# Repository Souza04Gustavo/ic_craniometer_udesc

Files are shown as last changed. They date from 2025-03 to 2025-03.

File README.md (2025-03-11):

# Craniômetro Digital - Projeto de Pesquisa UDESC (CCT & CEFID)

## Sobre o Projeto

Este repositório contém o desenvolvimento de um craniômetro digital, um protótipo inovador criado para auxiliar medições cranianas de bebês com maior precisão e eficiência em comparação com métodos manuais. O projeto é fruto de uma parceria entre a Universidade do Estado de Santa Catarina (UDESC) - Centro de Ciências Tecnológicas (CCT), Joinville, e a UDESC - Centro de Ciências da Saúde e do Esporte (CEFID). O desenvolvimento foi realizado por Gustavo de Souza e Grasiela Ferreira.

## Motivação

A medição da cabeça de bebês é um parâmetro essencial para monitoramento do crescimento e identificação de possíveis alterações no desenvolvimento craniano. Métodos tradicionais, como o uso de fita métrica, estão sujeitos a variações e imprecisões humanas. O craniômetro digital foi desenvolvido para:

Otimizar medições em clínicas e hospitais;

Reduzir erros humanos ao proporcionar um método padronizado e automatizado;

Aumentar a precisão nas medições cranianas;

Facilitar a obtenção e o registro dos dados para acompanhamento do crescimento infantil.

## Visão superior do protótipo

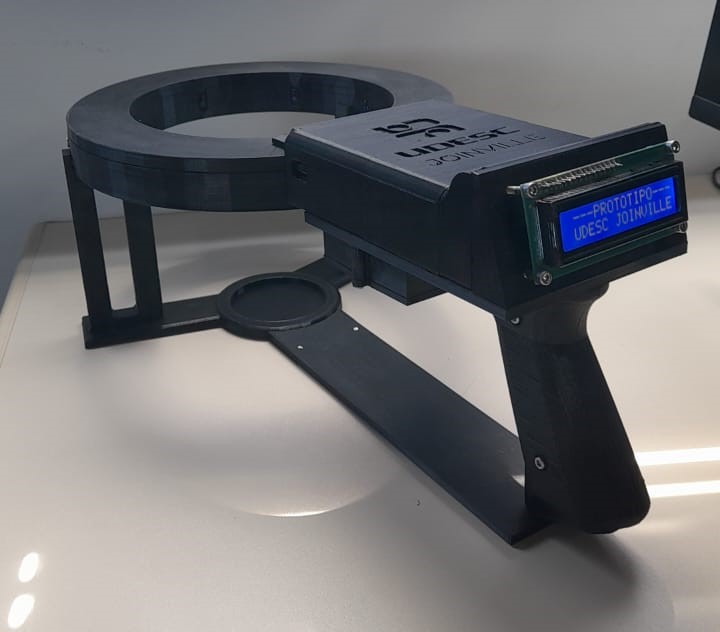
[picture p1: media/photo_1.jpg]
equipament photo


## Componentes Utilizados

| Componente | Descrição |
|---|---|
|**TCRT5000 (x8)** | Sensores infravermelhos para medir distâncias  |
|**MPU6050** | Módulo acelerômetro e giroscópio para estabilidade |
|**Display OLED** | Exibição das medições em tempo real |
| **Pilhas** | Alimentação portátil do equipamento |

## Operação do Equipamento

O funcionamento do craniômetro digital segue três etapas principais:

1. **Calibração:**

      - Antes de iniciar as medições, o equipamento passa por um processo de calibração utilizando peças impressas em 3D. Isso garante que os sensores estejam corretamente ajustados para obter medições precisas.

2. **Medição:**

      - O equipamento é posicionado ao redor da cabeça do bebê.

      - A criança utiliza uma faixa de lycra branca, o que melhora a captação das medições pelos sensores infravermelhos.

      - Os 8 sensores TCRT5000 medem as distâncias entre eles e a superfície da cabeça da criança.

      - O módulo MPU6050 auxilia na estabilização do equipamento, compensando pequenos movimentos involuntários.  

      - Os valores das medições são exibidos em tempo real no display OLED.

3. **Processamento e Armazenamento:**

      - Após a finalização da medição, os dados coletados são processados.

      - As informações são enviadas para um computador para futuras manipulações, armazenamento e exibição.

      - Isso permite a criação de um histórico de medições e facilita a análise do crescimento craniano da criança ao longo do tempo.

## Aplicações

Consultórios pediátricos e neonatais;

Hospitais e maternidades;

Pesquisas sobre desenvolvimento infantil;

Monitoramento de assimetrias cranianas.

## Licença

Este projeto é de código aberto e está disponível sob a licença MIT. Sinta-se à vontade para contribuir!

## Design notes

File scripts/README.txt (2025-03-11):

Site com todas as informações a respeito do ESP32: https://blog.smartkits.com.br/esp32-pinout-guia-basico-de-gpios/

-> Recomendo a leitura antes de iniciar a manipular os pinos do esp pois eles possuem muitas especificações que demorei pra descobrir e esse site me auxiliou.

INFORMAÇÕES SOBRE OS PINOS ESP32:

NÃO USAR: GPIOS 6 a 12 (usados para memoria flash)
Pinos alerta: 34, 35, 36, 39 (somente entrada)
Pinos para evitar se possível: 1, 3, 5, 14, 15 (não descobri o motivo)

PINOS USADOS NA PLACA V1:
#define sensor1 32 // (1) sensor na placa principal
#define sensor2 25 // (2) primeira placa a esquerda
#define sensor3 26 // (3) segunda placa a esquerda 
#define sensor4 27 // (4) terceira placa a esquerda
#define sensor5 13 // (5) quarta placa (de frente pra principal)
#define sensor6 14 // (6) terceira placa a direita 
#define sensor7 35 // (7) segundo a direita
#define sensor8 34 // (8) primeiro a direita

#define led1 23
#define led2 33
#define led3 16
#define led4 17
#define led5 15
#define led6 18
#define led7 19
#define led8 4

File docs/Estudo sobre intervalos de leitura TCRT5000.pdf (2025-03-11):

### Relatório do Sensor TCRT5000

Aluno: Gustavo de Souza

Pontos importantes sobre o sensor que devemos levar em consideração quando buscamos precisão na leitura utilizando menores intervalos de acionamento e desligamento do LED:

- Detecção rápida e precisa do tecido;
- Reduzirão a vida útil do LED;
- Tempo de resposta mais rapido a mudanças;
- Mais suscetíveis a interferências de ruídos;
- Calibração frequente para garantir a operação precisa;

### Testes

Fórmula da Variância Populacional:

Levando como amostra 50 leituras do sensor e que os intervalos como “10ms” representam o tempo entre o acionamento e desligamento do sensor, e os intervalos como 5_5 representam uma fusão do número de leituras com o LED desligado antes de ligá-lo novamente.

Resultados:

1,5 cm de distância:

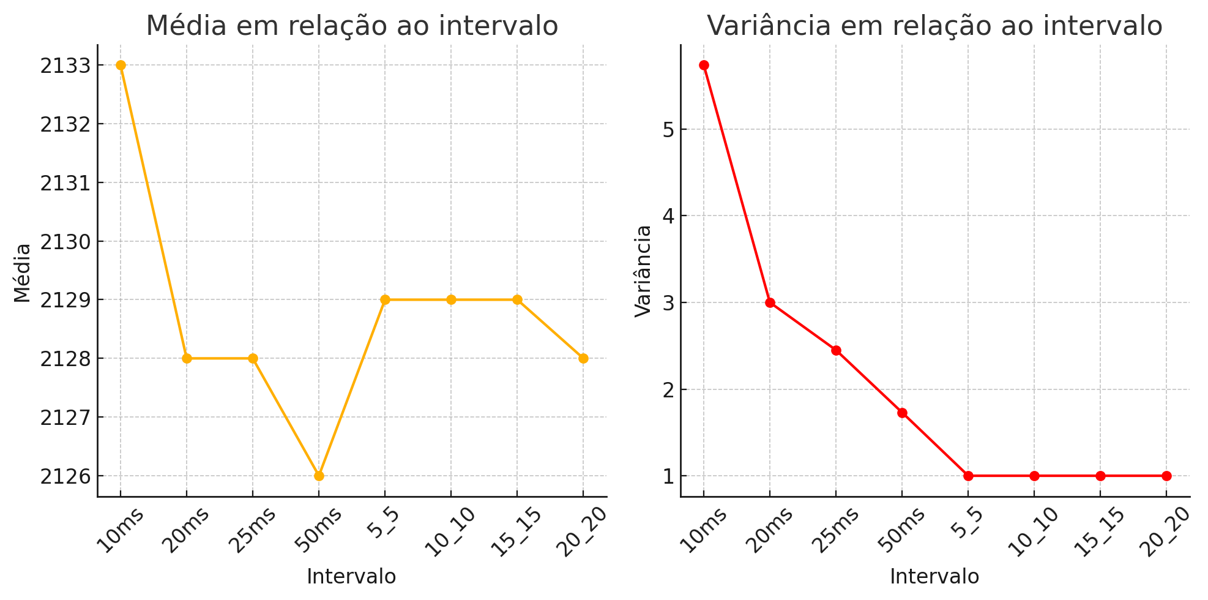
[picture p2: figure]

Intervalo | Média | Variância
10ms | 2133.00 | 5.74
20ms | 2128.00 | 3.00
25ms | 2128.00 | 2.45
50ms | 2126.00 | 1.73
5_5 | 2129.00 | 1.00
10_10 | 2129.00 | 1.00
15_15 | 2129.00 | 1.00
20_20 | 2128.00 | 1.00

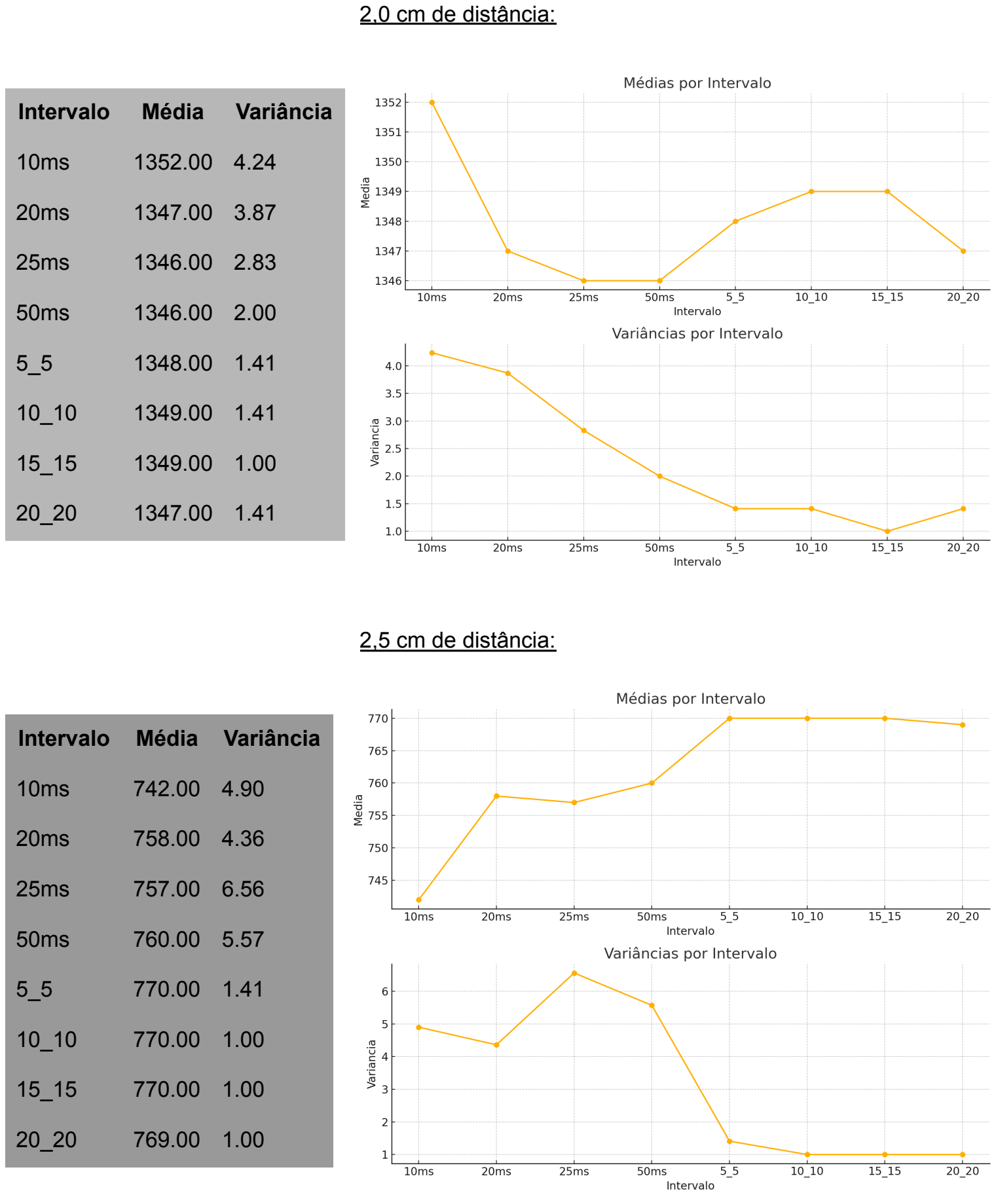
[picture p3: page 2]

2,0 cm de distância:

Intervalo | Média | Variância
10ms | 1352.00 | 4.24
20ms | 1347.00 | 3.87
25ms | 1346.00 | 2.83
50ms | 1346.00 | 2.00
5_5 | 1348.00 | 1.41
10_10 | 1349.00 | 1.41
15_15 | 1349.00 | 1.00
20_20 | 1347.00 | 1.41

2,5 cm de distância:

Intervalo | Média | Variância
10ms | 742.00 | 4.90
20ms | 758.00 | 4.36
25ms | 757.00 | 6.56
50ms | 760.00 | 5.57
5_5 | 770.00 | 1.41
10_10 | 770.00 | 1.00
15_15 | 770.00 | 1.00
20_20 | 769.00 | 1.00

3,0 cm de distância:

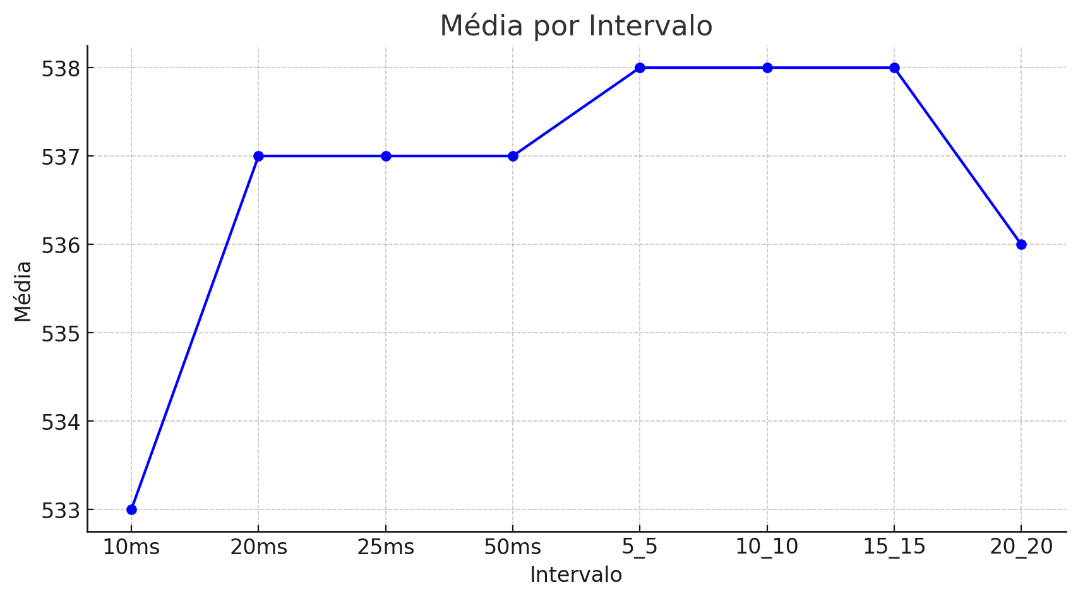
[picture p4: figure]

Intervalo | Média | Variância
10ms | 533.0 | 5.10
20ms | 537.0 | 4.00
25ms | 537.0 | 2.83

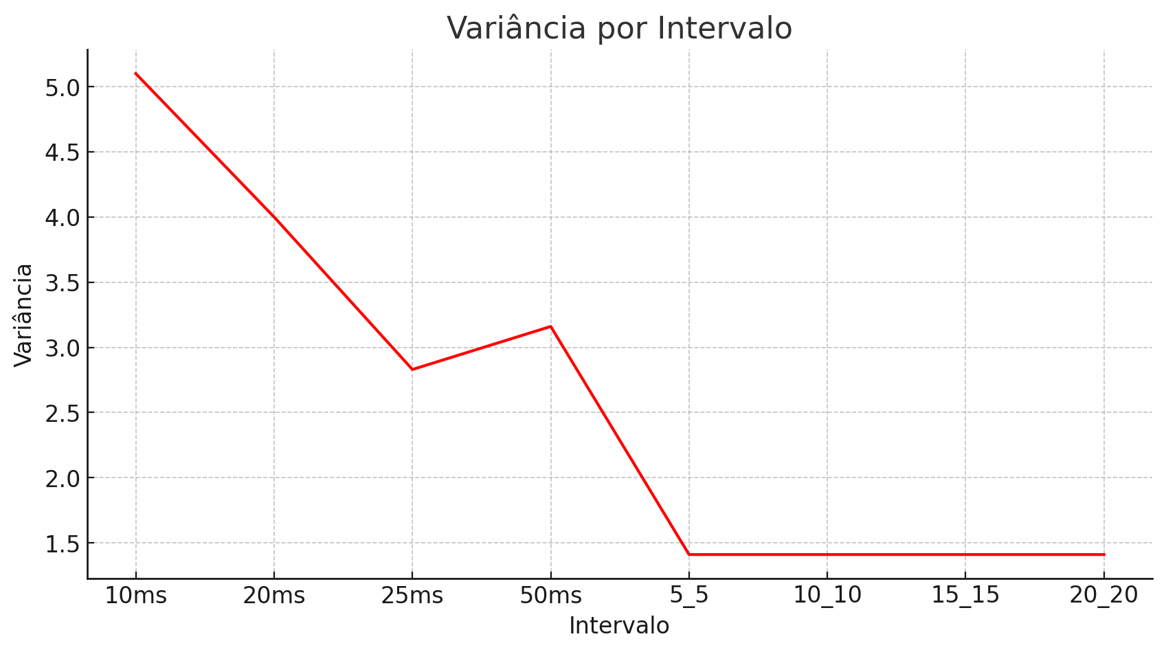
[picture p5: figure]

50ms | 537.0 | 3.16
5_5 | 538.0 | 1.41
10_10 | 538.0 | 1.41
15_15 | 538.0 | 1.41
20_20 | 536.0 | 1.41

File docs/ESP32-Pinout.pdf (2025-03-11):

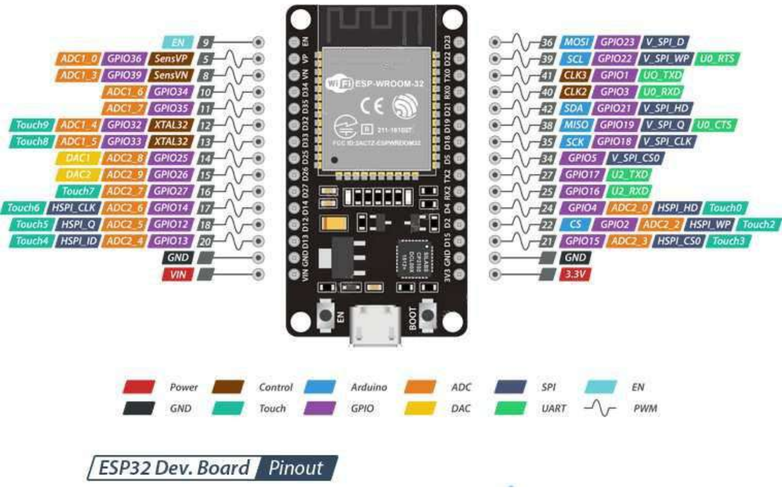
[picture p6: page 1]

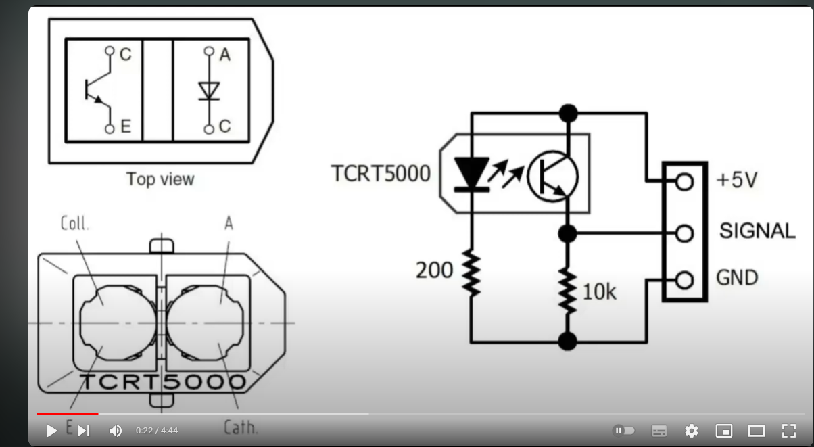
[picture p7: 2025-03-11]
docs/Pinout TCRT5000.png

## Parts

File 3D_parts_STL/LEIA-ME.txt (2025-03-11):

Nessa pasta estão os modelos STL que foram retirados do Inventor 2024 e impressos utilizando o fatiador Ultimaker Cura 5.7.1

Os nomes das peças são autointerpretativos e a classicação "V1" se refere a primeira versão do equipamento que foi desenvolvida no final de 2024 por Gustavo de Souza e Grasiela, já a "V2" foi iniciada pelo bolsista Gustavo e continuada por Pedro Henrique no inicio de 2025.

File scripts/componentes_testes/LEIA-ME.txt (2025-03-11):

Todos os códigos desta pasta servem apenas como testes para verificar se o esp e os componentes estão operando normalmente.

Obs: O código "teste_mpu6050_server" é oriundo do site: https://RandomNerdTutorials.com/esp32-mpu-6050-web-server/
-> Com esse código o esp32 cria um web server e nele exibe em 3D a rotação do equipamento, apesar de ser muito interessante, atualmente não há muita necessidade de uso de um aplicação como essa mas vale a pena deixar registrado para futuras implementações.

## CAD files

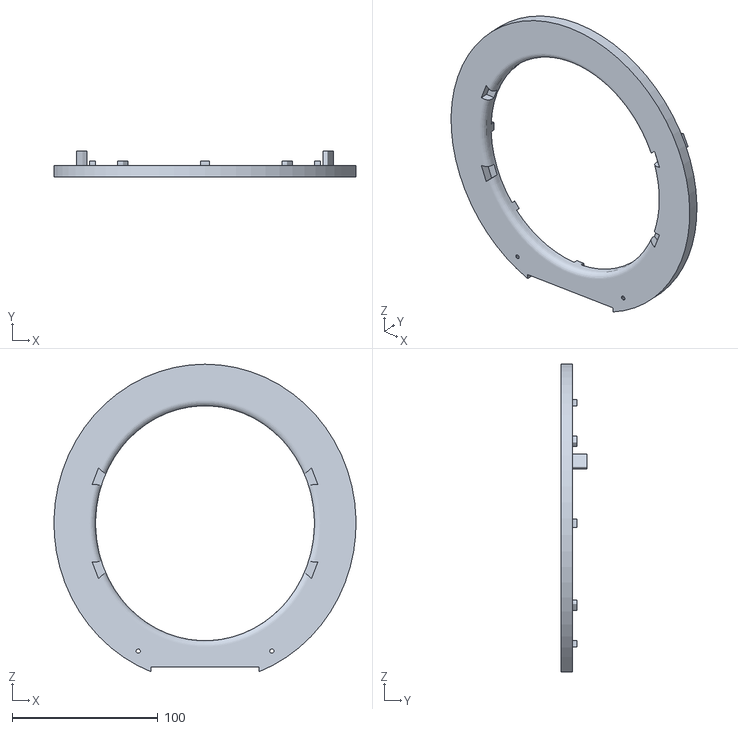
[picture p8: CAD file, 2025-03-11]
3D_parts_STL/tampa_anel_v2.stl
207.0 x 18.0 x 210.8

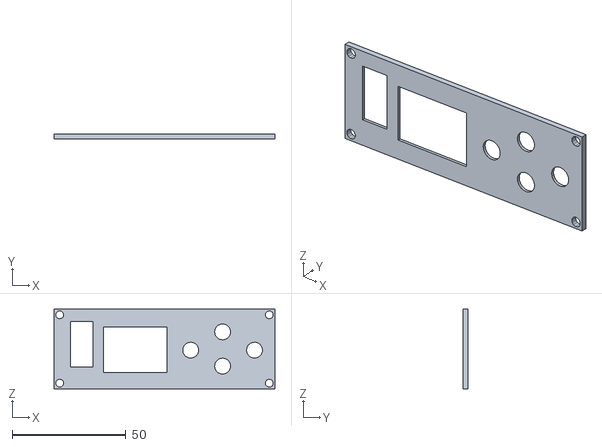
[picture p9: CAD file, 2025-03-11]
3D_parts_STL/tampa_lcd_botoes.stl
97.0 x 2.00 x 35.0

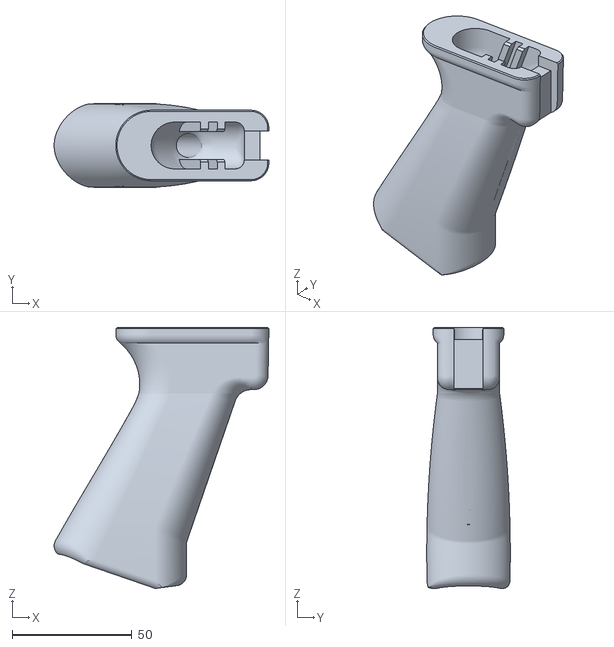
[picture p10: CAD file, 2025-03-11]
3D_parts_STL/Empunhadura_completa.stl
89.8 x 34.9 x 109.1

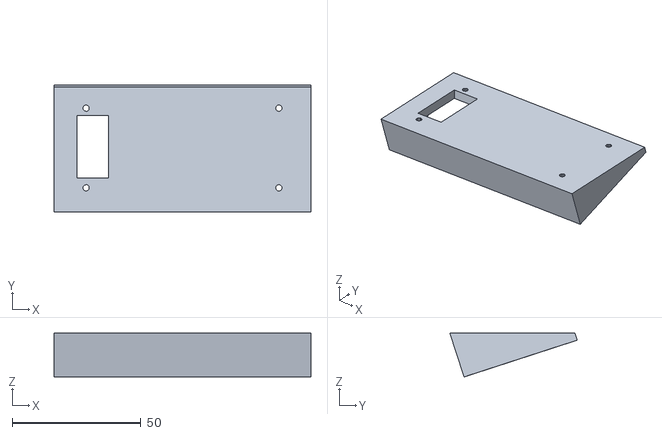
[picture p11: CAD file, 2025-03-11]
3D_parts_STL/suporte_LCD.stl
100.0 x 49.6 x 17.1

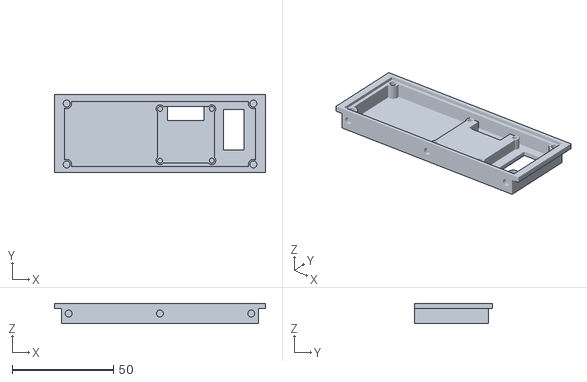
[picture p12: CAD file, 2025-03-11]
3D_parts_STL/suporte_lcd_botoes.stl
104.0 x 38.5 x 10.0

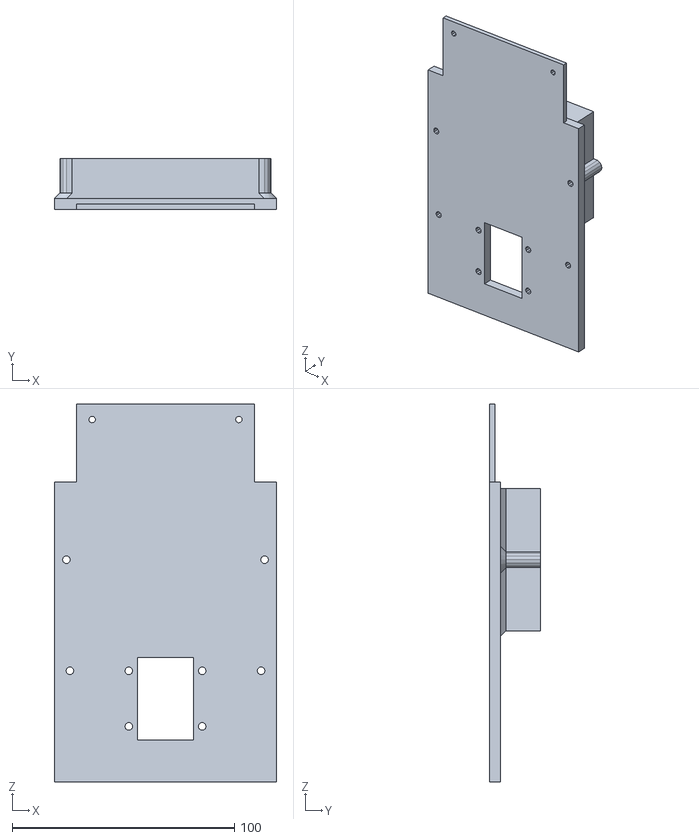
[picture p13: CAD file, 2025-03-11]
3D_parts_STL/suporte_pilhas.stl
100.0 x 23.0 x 170.0

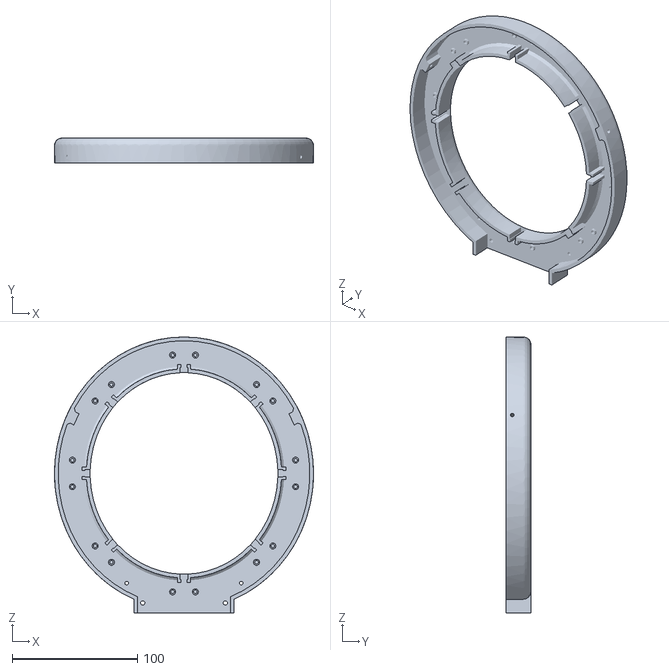
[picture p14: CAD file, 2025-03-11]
3D_parts_STL/anel_v2.stl
207.0 x 20.0 x 220.5

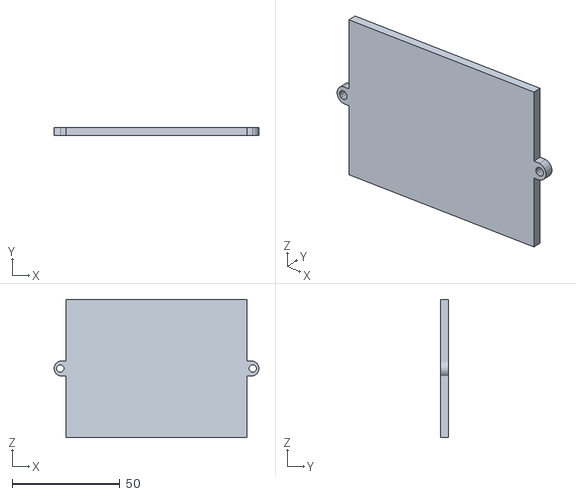
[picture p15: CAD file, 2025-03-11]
3D_parts_STL/tampa_pilha.stl
94.9 x 3.50 x 64.0

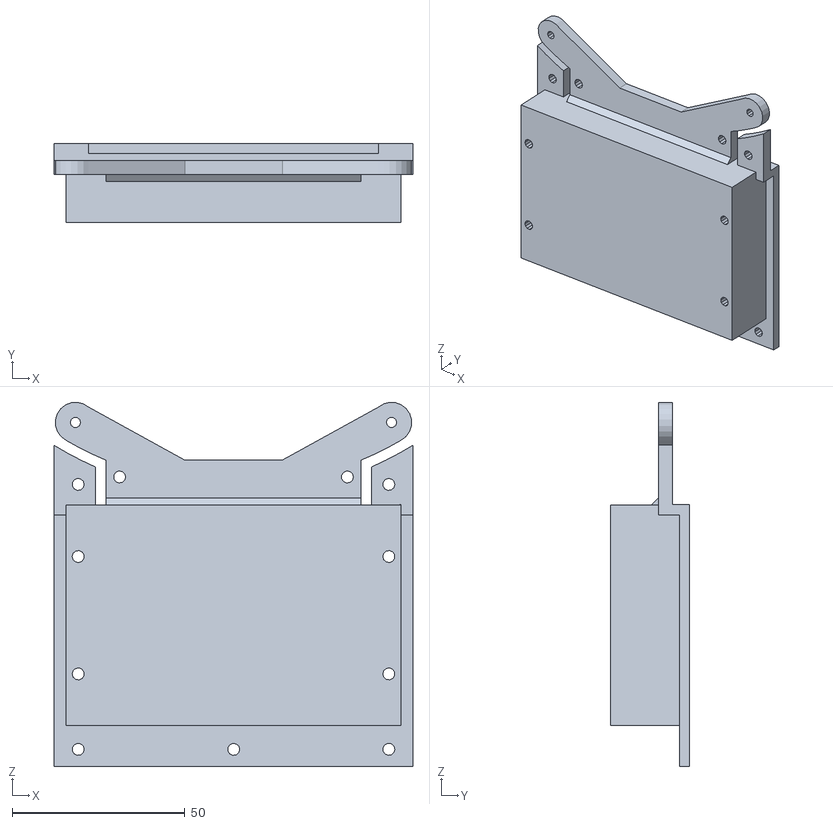
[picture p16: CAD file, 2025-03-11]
3D_parts_STL/peca_principal_v2.stl
104.0 x 23.0 x 105.5

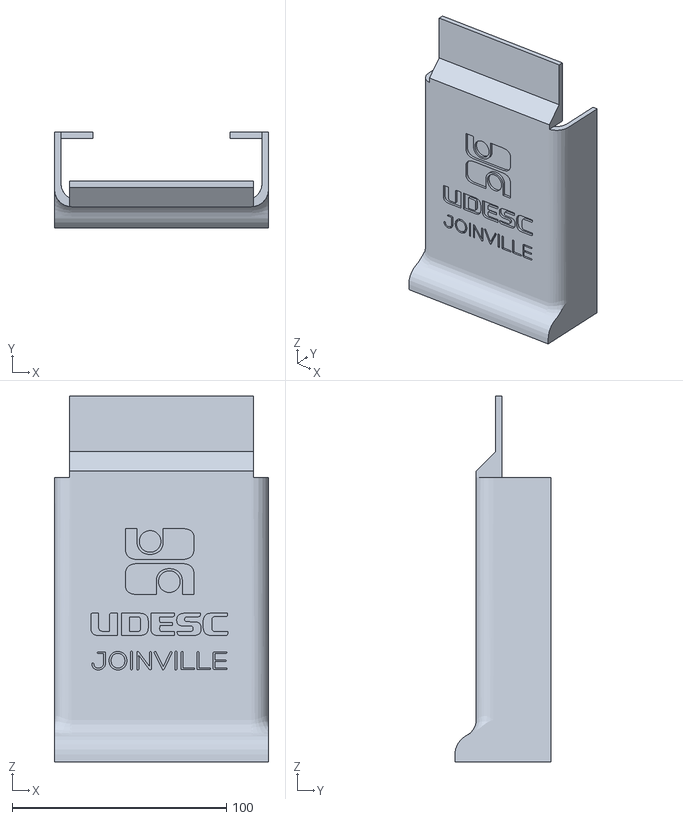
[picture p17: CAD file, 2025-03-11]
3D_parts_STL/tampa_UDESC_JOINVILLE.stl
100.0 x 45.0 x 171.0

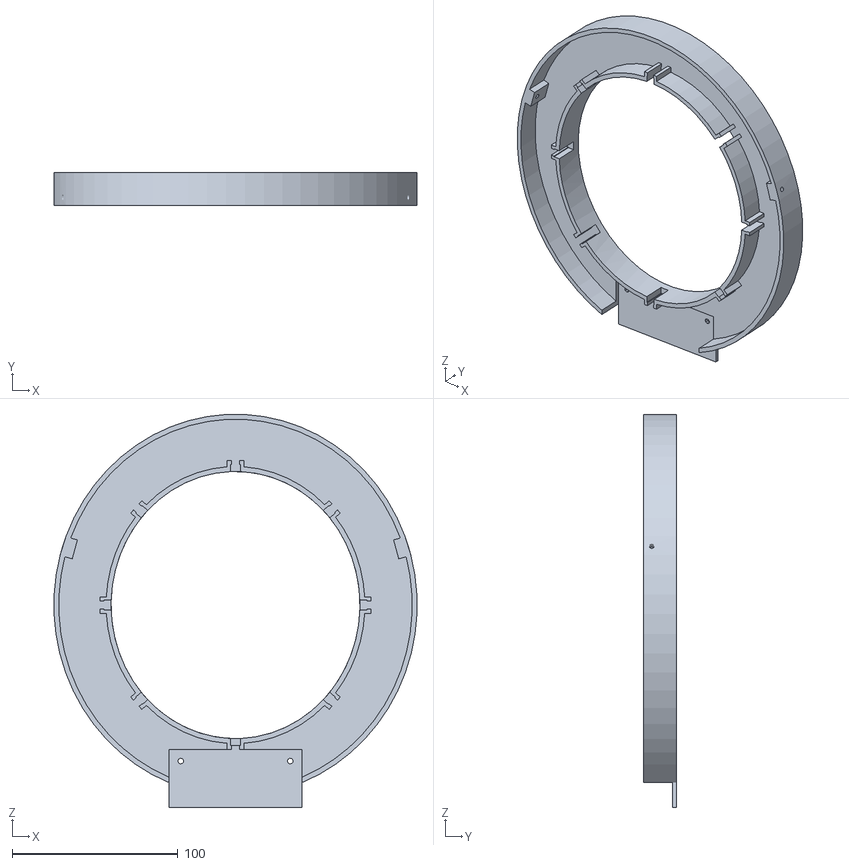
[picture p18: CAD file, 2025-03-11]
3D_parts_STL/anel.stl
218.7 x 20.0 x 236.9

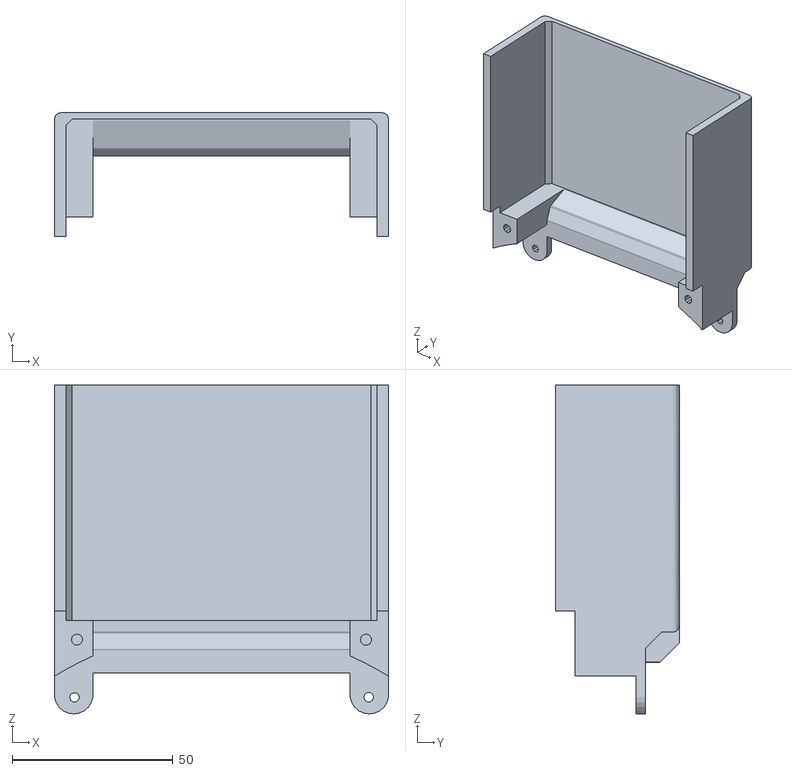
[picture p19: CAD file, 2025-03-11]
3D_parts_STL/tampa_principal_v2.stl
104.0 x 38.5 x 102.4

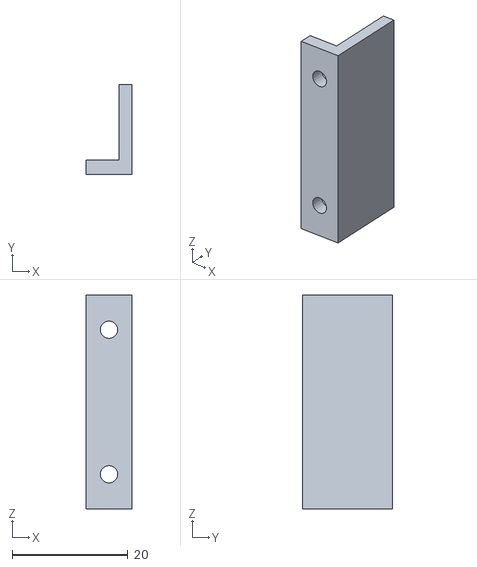
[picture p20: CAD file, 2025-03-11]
3D_parts_STL/suporte_empunhadura.stl
8.00 x 15.5 x 37.0

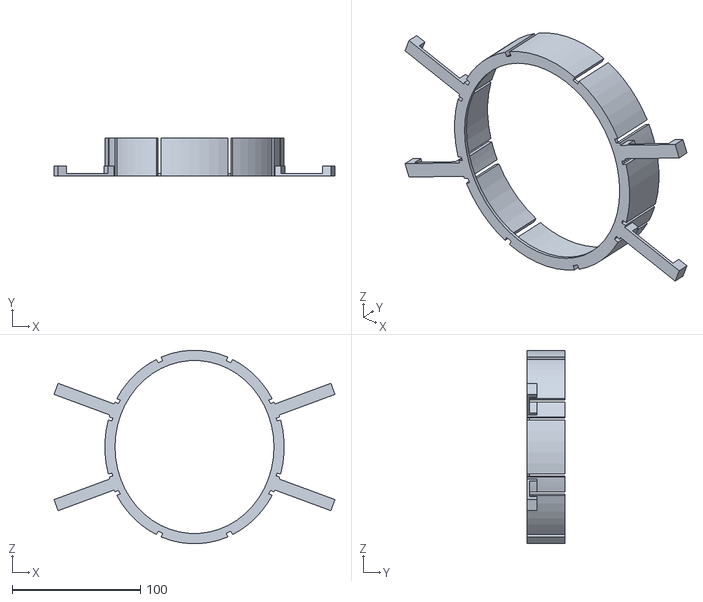
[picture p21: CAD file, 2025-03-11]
3D_parts_STL/calibrador(0,5cm).stl
219.2 x 30.0 x 150.8

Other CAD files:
3D_parts_STL/tampa_principal_com_udesc_v2.stl
3D_parts_STL/empunhadura_fatiada.stl
3D_parts_STL/calibrador(1,0cm).stl
3D_parts_STL/tampa_SEM_UDESC_JOINVILLE.stl
3D_parts_IPT/Montagem_ic.iam
3D_parts_IPT/Montagem_v2.iam
3D_parts_IPT/OldVersions/Montagem_ic.0004.iam
3D_parts_IPT/OldVersions/Montagem_v2.0001.iam
3D_parts_IPT/OldVersions/anel.0009.ipt
3D_parts_IPT/OldVersions/anel_v2.0017.ipt
3D_parts_IPT/OldVersions/calibracao(0,5cm).0001.ipt
3D_parts_IPT/OldVersions/calibracao(1,0cm).0002.ipt
3D_parts_IPT/OldVersions/peca_principal.0004.ipt
3D_parts_IPT/OldVersions/peca_principal_v2.0004.ipt
3D_parts_IPT/OldVersions/suporte_lcd_botoes.0004.ipt
3D_parts_IPT/OldVersions/suporte_peca2.0004.ipt
3D_parts_IPT/OldVersions/tampa_anel.0002.ipt
3D_parts_IPT/OldVersions/tampa_anel_v2.0004.ipt
3D_parts_IPT/OldVersions/tampa_lcd_botoes.0001.ipt
3D_parts_IPT/OldVersions/tampa_principal_v2.0003.ipt
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

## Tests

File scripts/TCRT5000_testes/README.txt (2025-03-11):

Todos os códigos dessa pasta funcionam individualmente, porem o código em pyhton denominado "gráfico" serve como exibição gráfica dos pontos de calibração obtidos no código "calculo_automatizado_com_calibracao_manual_1_sensor.ino", porem o processo de plotagem não é automatizado. Para exibir corretamente o gráfico que representa a função linearizada de cada sensor deve-se rodar o código ".ino" e nele serão salvos e exibidos os valores médios dos sensores obtidos na calibração, esses valores devem ser inseridos manualmente no código python para que o mesmo plote corretamente o gráfico.

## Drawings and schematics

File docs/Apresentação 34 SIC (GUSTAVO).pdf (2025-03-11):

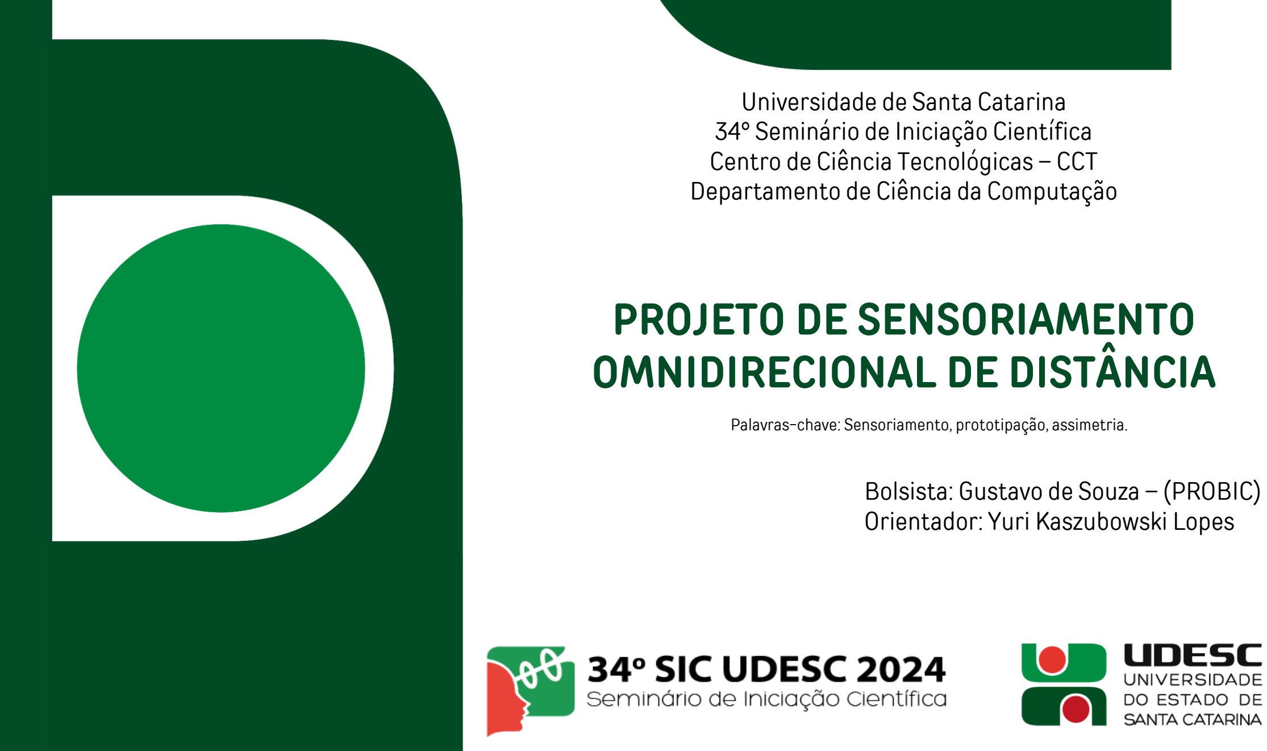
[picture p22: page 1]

### Universidade de Santa Catarina 34° Seminário de Iniciação Científica Centro de Ciência Tecnológicas – CCT Departamento de Ciência da Computação

# PROJETO DE SENSORIAMENTO OMNIDIRECIONAL DE DISTÂNCIA

### Bolsista: Gustavo de Souza – (PROBIC) Orientador: Yuri Kaszubowski Lopes

Palavras-chave: Sensoriamento, prototipação, assimetria.

## ASSIMETRIA CRANIANA

## Deformidade no crânio causada por

pressões externas no crânio do bebê.

## O QUE É?

## Figura 1 - Fotografias de assimetria craniana vista superior e lateral

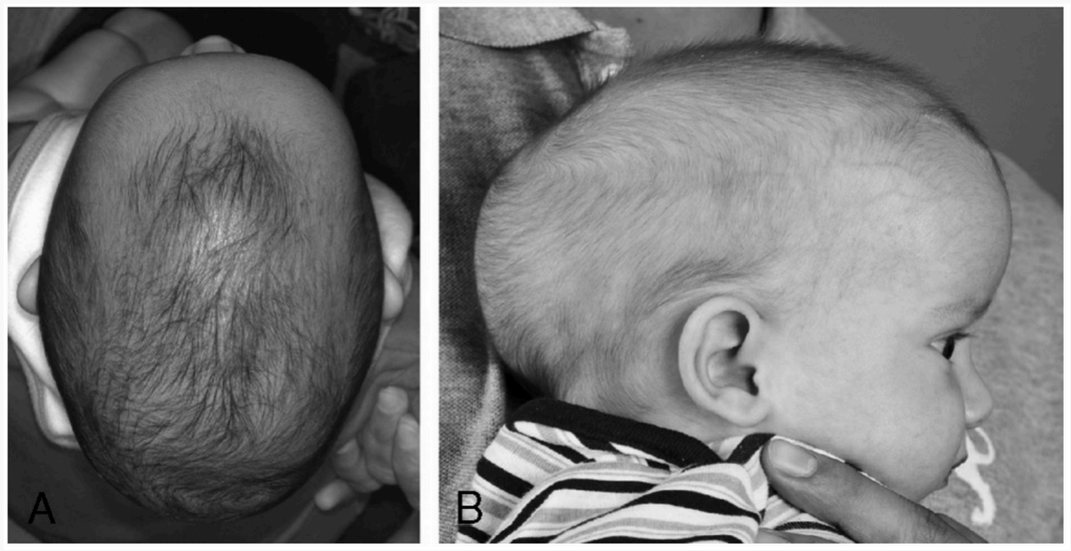
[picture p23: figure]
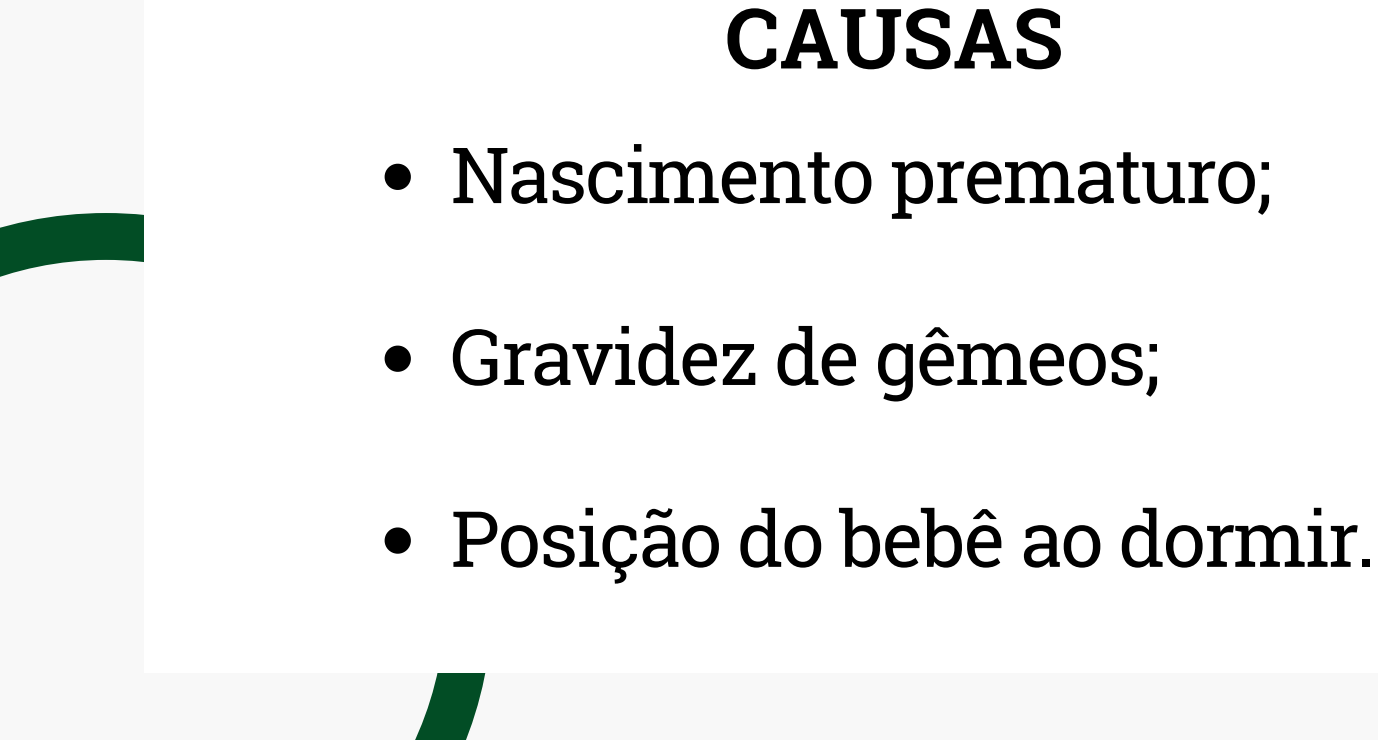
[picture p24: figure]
Nascimento prematuro;; Gravidez de gêmeos;; Posição do bebê ao dormir.; CAUSAS

Fonte: Rogers (2011, p. 9-16).

## TIPOS DE ASSIMETRIA CRANIAL POSICIONAL

## Figura 2 - Tipos de assimetria

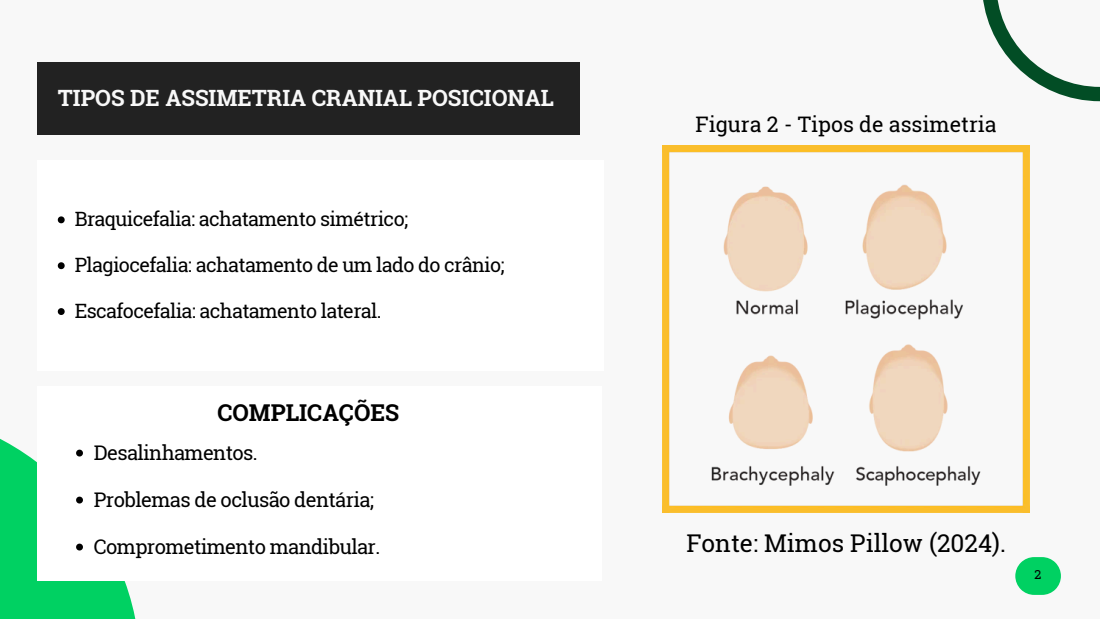
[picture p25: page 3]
COMPLICAÇÕES

Braquicefalia: achatamento simétrico;
Plagiocefalia: achatamento de um lado do crânio;
Escafocefalia: achatamento lateral.

Desalinhamentos.
Problemas de oclusão dentária;
Comprometimento mandibular.

Fonte: Mimos Pillow (2024).

# DIAGNÓSTICO E LIMITAÇÕES

## Figura 3 - Demonstração de medição

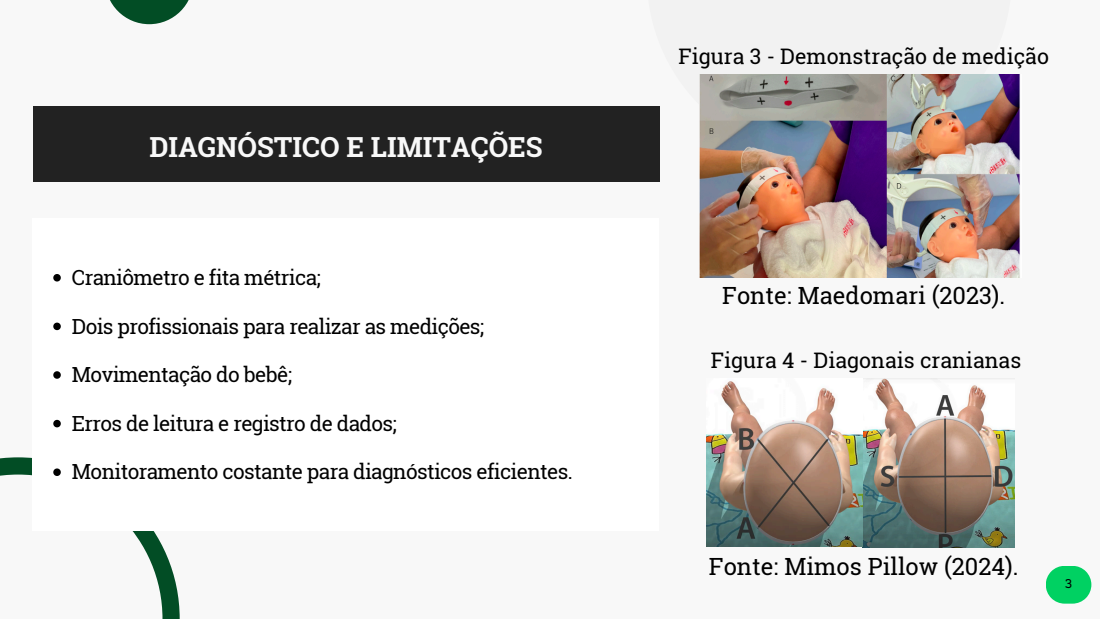
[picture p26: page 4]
Fonte: Maedomari (2023).

Craniômetro e fita métrica;
Dois profissionais para realizar as medições;
Movimentação do bebê;
Erros de leitura e registro de dados;
Monitoramento costante para diagnósticos eficientes.

Figura 4 - Diagonais cranianas

Fonte: Mimos Pillow (2024).

# PROTÓTIPO

## Figura 5 - Sensor TCRT5000

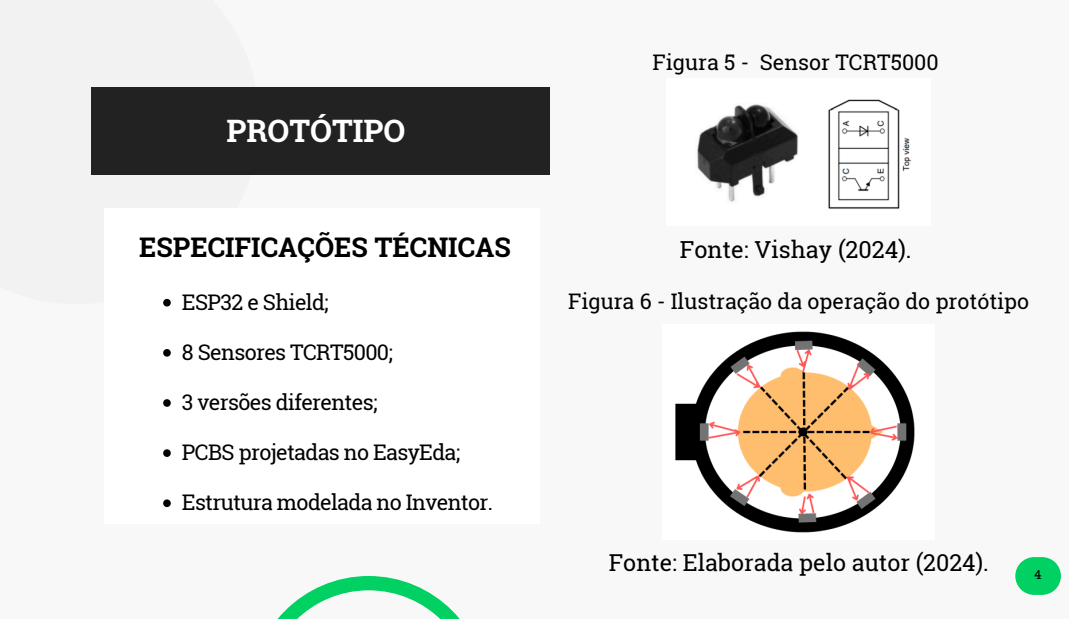
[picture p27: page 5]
ESPECIFICAÇÕES TÉCNICAS; Fonte: Vishay (2024).

ESP32 e Shield;
8 Sensores TCRT5000;
3 versões diferentes;
PCBS projetadas no EasyEda;
Estrutura modelada no Inventor.

Figura 6 - Ilustração da operação do protótipo

Fonte: Elaborada pelo autor (2024).

# DIFERENCIAIS

### Figura 7 - Vista superior do protótipo

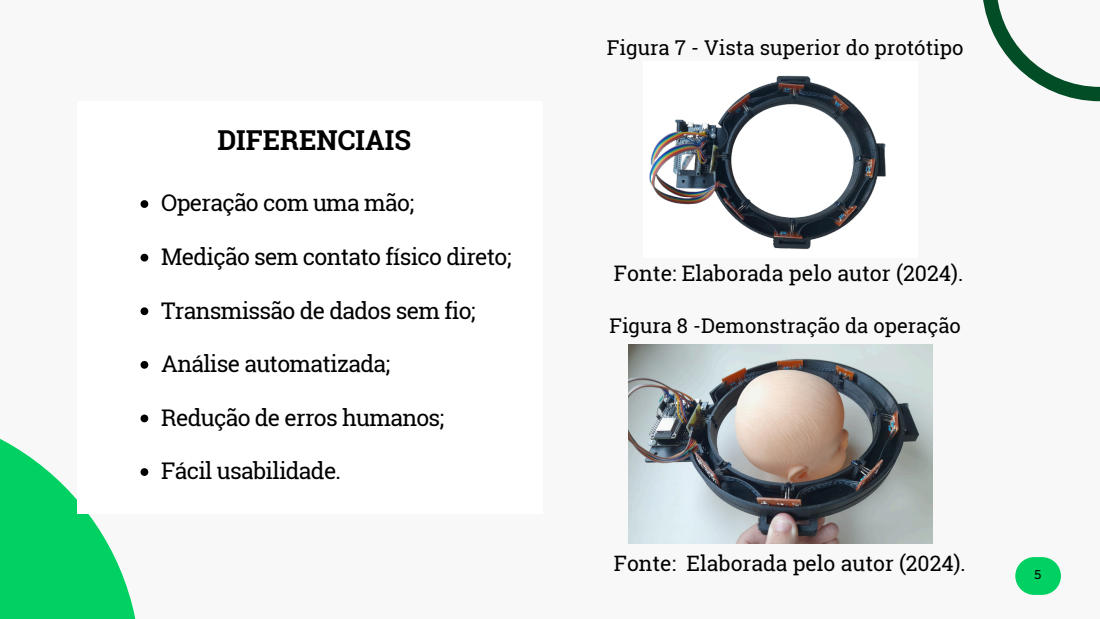
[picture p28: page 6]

Operação com uma mão;
Medição sem contato físico direto;
Transmissão de dados sem fio;
Análise automatizada;
Redução de erros humanos;
Fácil usabilidade.

Fonte: Elaborada pelo autor (2024).

Figura 8 -Demonstração da operação

# TRABALHOS FUTUROS

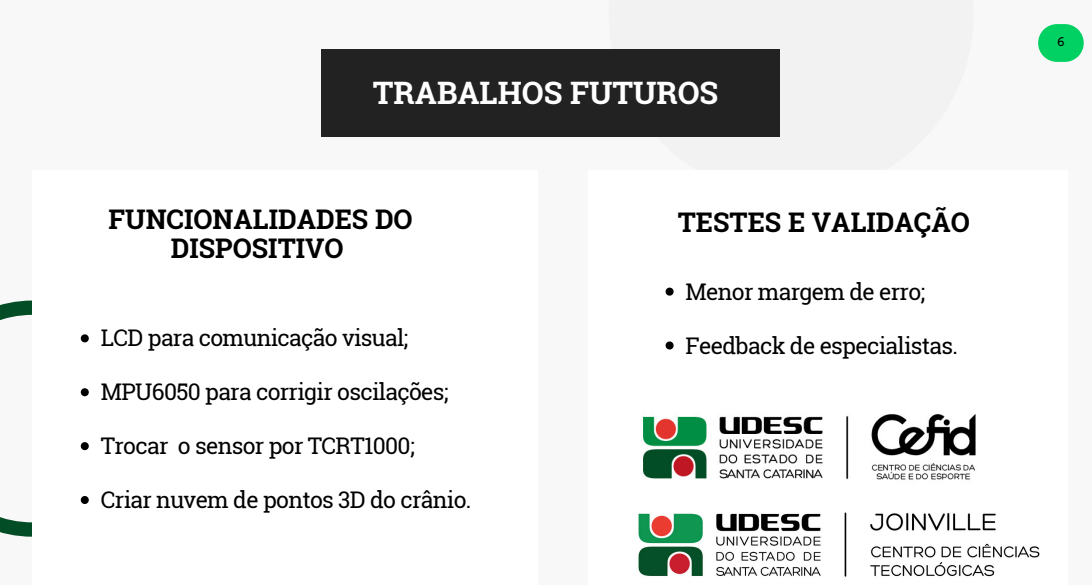
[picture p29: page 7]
FUNCIONALIDADES DO DISPOSITIVO; TESTES E VALIDAÇÃO

Menor margem de erro;

Feedback de especialistas. LCD para comunicação visual;
MPU6050 para corrigir oscilações;
Trocar o sensor por TCRT1000;
Criar nuvem de pontos 3D do crânio.

## REFERÊNCIAS

Gary F Rogers. 2011. Deformational plagiocephaly, brachycephaly, and scaphocephaly. Part I: terminology, diagnosis, and etiopathogenesis. Journal of Cranio-facial Surgery 22, 1 (2011), 9–16. Mimos Pillow. Mimos Baby Pillow. Disponível em: https://mimosbabypillow.com/. Acesso em: 18 out. 2024. MAEDOMARI, T.; MIYABAYASHI, H.; TANAKA, Y.; MUKAI, C.; NAKANOMORI, A.; SAITO, K.; KATO, R.; NOTO, T.; NAGANO, N.; MORIOKA, I. Cranial shape measurements obtained using a caliper and elastic bands are useful for brachycephaly and deformational plagiocephaly

screening. Journal of Clinical Medicine, v. 12, n. 8, 2023. Disponível em: https://doi.org/10.3390/jcm12082787. Acesso em: 18 out. 2024. VISHAY , INC. TCRT5000, TCRT5000L: Reflective Optical Sensor with Transistor Output. Disponível em:

https://www.vishay.com/docs/83760/tcrt5000.pdf. Acesso em: 18 out. 2024.

# Agradecimentos

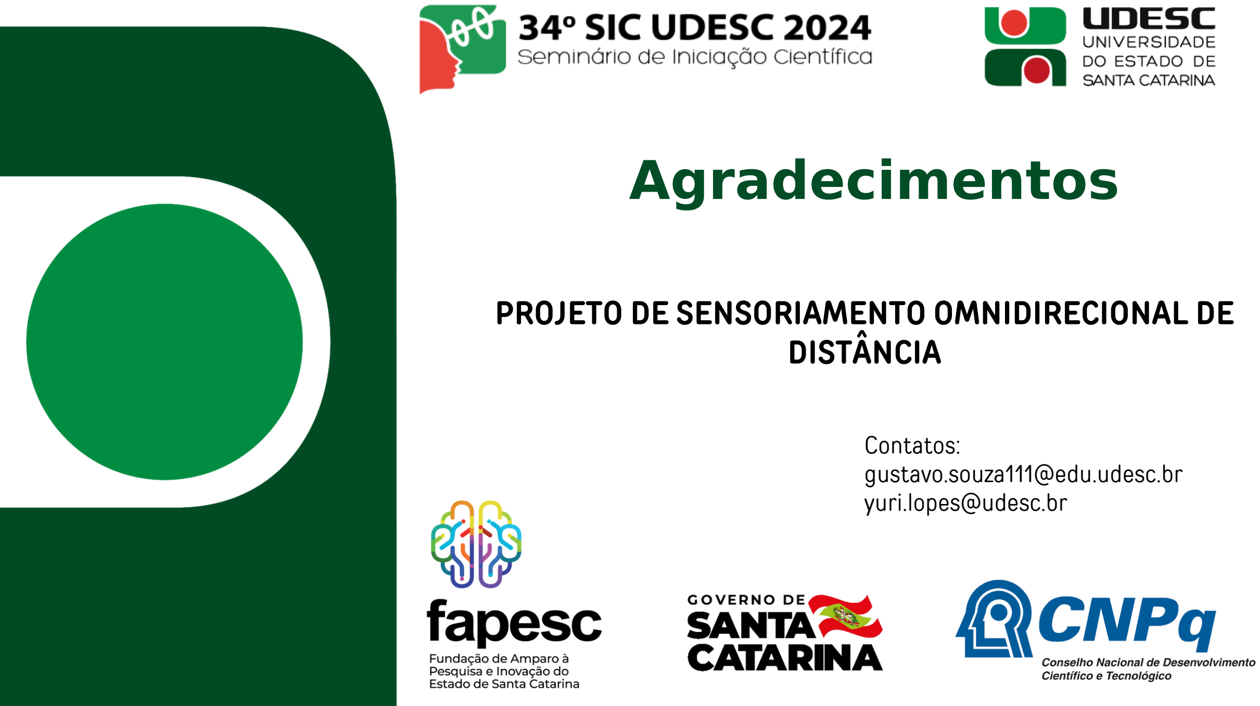
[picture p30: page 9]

## PROJETO DE SENSORIAMENTO OMNIDIRECIONAL DE DISTÂNCIA

### Contatos: gustavo.souza111@edu.udesc.br yuri.lopes@udesc.br

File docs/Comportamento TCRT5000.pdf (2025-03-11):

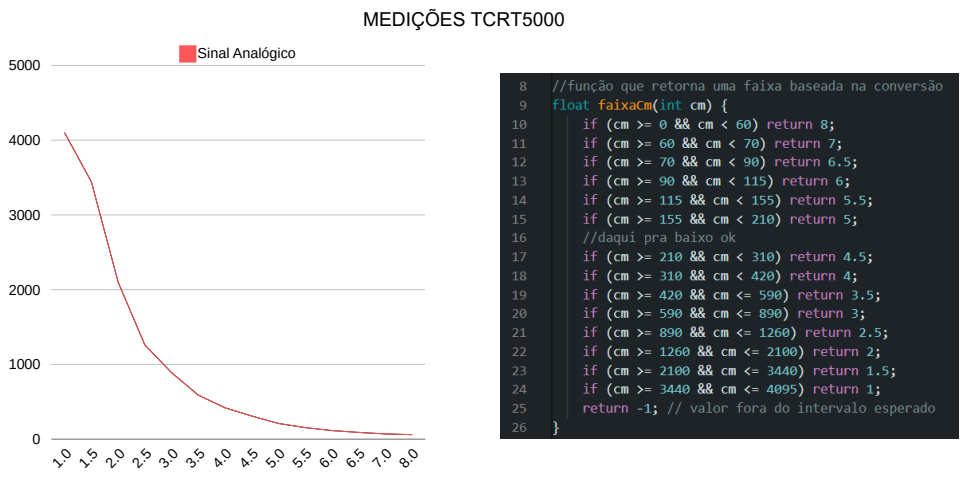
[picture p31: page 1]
Sinal Analógico; MEDIÇÕES TCRT5000

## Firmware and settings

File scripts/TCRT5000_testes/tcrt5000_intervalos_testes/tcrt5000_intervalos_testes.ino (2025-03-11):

#define sensor 34
#define led 32
#define montante 50

int inicio, noise, a, b, c, num, i;
float faixa;
int count = 0, soma = 0, soma_var = 0;
float media10, variancia10, media20, variancia20, media25, variancia25, media50, variancia50, media5_5, variancia5_5, media10_10, variancia10_10, media15_15, variancia15_15, media20_20, variancia20_20;
int leituras_intervalo;
int soma_a, soma_b, count2;
char incomingChar;
int vet[montante];


void setup() {
  pinMode(sensor, INPUT); 
  pinMode(led,OUTPUT);
  Serial.begin(115200); 
}

void loop() {
 /*--- PROGRAMA DE CALIBRAGEM TCRT5000 ---*/

  while (Serial.available() > 0) {
  // Lê o próximo caractere da porta serial
  Serial.println("Digite (1) para iniciar teste | Digite (2) para reiniciar");
  incomingChar = Serial.read();

  switch(incomingChar){

  //onde os testes de fato sao realizados
  case '1':

  //TESTE 1
  Serial.println("TESTE 10ms entre ON/OFF (20ms para cada leitura)");
      
  while(count < montante){
  digitalWrite(led, HIGH);
  delay(10);
  a = analogRead(sensor);
  digitalWrite(led, LOW);
  delay(10);
  b = analogRead(sensor);

  c = a - b;
  vet[count] = c;
  soma = soma + c;
  count++;
  Serial.print(c);       //denoised signal
  Serial.print("\t");
  Serial.print(count);         //noise+signal
  Serial.print("\t");
  Serial.println();
  }

  media10 = (soma/montante);
  Serial.println();
  Serial.print("Media(10ms):");
  Serial.print(media10);
  Serial.println();

  //calculando a variancia amostral
  for(i = 0; i < montante; i++){
    soma_var = soma_var + ( (vet[i] - media10)*(vet[i] - media10) );
  }
  
  variancia10 = sqrt(soma_var/(montante-1));
  Serial.print("Variancia(10ms):");
  Serial.print(variancia10);
  Serial.println();

  //TESTE 2
  soma = 0;
  count = 0;
  soma_var = 0;
  i = 0;
  for(i = 0; i < montante; i++){
    vet[i] = 0;
  }
  
  Serial.println("TESTE 20ms entre ON/OFF (40ms para cada leitura)");
      
  while(count < montante){
  digitalWrite(led, HIGH);
  delay(20);
  a = analogRead(sensor);
  digitalWrite(led, LOW);
  delay(20);
  b = analogRead(sensor);

  c = a - b;
  vet[count] = c;
  soma = soma + c;
  count++;
  Serial.print(c);       //denoised signal
  Serial.print("\t");
  Serial.print(count);         //noise+signal
  Serial.print("\t");
  Serial.println();
  }

  media20 = (soma/montante);
  Serial.println();
  Serial.print("Media(20ms):");
  Serial.print(media20);
  Serial.println();

  //calculando a variancia amostral
  for(i = 0; i < montante; i++){
    soma_var = soma_var + ( (vet[i] - media20)*(vet[i] - media20) );
  }
  variancia20 = sqrt(soma_var/(montante-1));
  Serial.print("Variancia(20ms):");
  Serial.print(variancia20);
  Serial.println();

  //TESTE 3
  soma = 0;
  count = 0;
  soma_var = 0;
  i = 0;
  for(i = 0; i < montante; i++){
    vet[i] = 0;
  }
  
  Serial.println("TESTE 25ms entre ON/OFF (50ms para cada leitura)");
      
  while(count < montante){
  digitalWrite(led, HIGH);
  delay(25);
  a = analogRead(sensor);
  digitalWrite(led, LOW);
  delay(25);
  b = analogRead(sensor);

  c = a - b;
  vet[count] = c;
  soma = soma + c;
  count++;
  Serial.print(c);       //denoised signal
  Serial.print("\t");
  Serial.print(count);         //noise+signal
  Serial.print("\t");
  Serial.println();
  }

  media25 = (soma/montante);
  Serial.println();
  Serial.print("Media(25ms):");
  Serial.print(media25);
  Serial.println();

  //calculando a variancia amostral
  for(i = 0; i < montante; i++){
    soma_var = soma_var + ( (vet[i] - media25)*(vet[i] - media25) );
  }
  variancia25 = sqrt(soma_var/(montante-1));
  Serial.print("Variancia(25ms):");
  Serial.print(variancia25);
  Serial.println();

  //TESTE 4
  soma = 0;
  count = 0;
  soma_var = 0;
  for(i = 0; i < montante; i++){
    vet[i] = 0;
  }
  
  Serial.println("TESTE 50ms entre ON/OFF (100ms para cada leitura)");
      
  while(count < montante){
  digitalWrite(led, HIGH);
  delay(50);
  a = analogRead(sensor);
  digitalWrite(led, LOW);
  delay(50);
  b = analogRead(sensor);

  c = a - b;
  vet[count] = c;
  soma = soma + c;
  count++;
  Serial.print(c);       //denoised signal
  Serial.print("\t");
  Serial.print(count);         //noise+signal
  Serial.print("\t");
  Serial.println();
  }

  media50 = (soma/montante);
  Serial.println();
  Serial.print("Media(50ms):");
  Serial.print(media50);
  Serial.println();

  //calculando a variancia amostral
  for(i = 0; i < montante; i++){
    soma_var = soma_var + ( (vet[i] - media50)*(vet[i] - media50) );
  }
  variancia50 = sqrt(soma_var/(montante-1));
  Serial.print("Variancia(50ms):");
  Serial.print(variancia50);
  Serial.println();

  //TESTE 5 (SOMATORIO)
  leituras_intervalo = 5;
  soma = 0;
  count = 0;
  soma_var = 0;
  for(i = 0; i < montante; i++){
    vet[i] = 0;
  }

  Serial.println("TESTE 5 leituras entre ON/OFF");

  while(count < montante){

  soma_a = 0;
  digitalWrite(led, HIGH);
  delay(1);
  while(count2 < leituras_intervalo){
    a = analogRead(sensor);
    soma_a = soma_a + a;
    count2++;
  }

  soma_b = 0;
  count2 = 0;
  digitalWrite(led, LOW);
  delay(1);
  while(count2 < leituras_intervalo){
    b = analogRead(sensor);
    soma_b = soma_b + b;
    count2++;
  }
  count2 = 0;

  c = ((soma_a/5) - (soma_b/5));
  vet[count] = c;
  soma = soma + c;
  count++;
  Serial.print(c);       //denoised signal
  Serial.print("\t");
  Serial.print(count);         //noise+signal
  Serial.print("\t");
  Serial.println();
  
  }//fim do while

  media5_5 = (soma/montante);
  Serial.println();
  Serial.print("Media(5_5):");
  Serial.print(media5_5);
  Serial.println();

  //calculando a variancia amostral
  for(i = 0; i < montante; i++){
    soma_var = soma_var + ( (vet[i] - media5_5)*(vet[i] - media5_5) );
  }
  variancia5_5 = sqrt(soma_var/(montante-1));
  Serial.print("Variancia(5_5):");
  Serial.print(variancia5_5);
  Serial.println();

  //TESTE 6 (SOMATORIO 2)
  leituras_intervalo = 10;
  soma = 0;
  count = 0;
  soma_var = 0;
  count2 = 0;
  for(i = 0; i < montante; i++){
    vet[i] = 0;
  }

  Serial.println("TESTE 10 leituras entre ON/OFF");

  while(count < montante){

  soma_a = 0;
  digitalWrite(led, HIGH);
  delay(1);
  while(count2 < leituras_intervalo){
    a = analogRead(sensor);
    soma_a = soma_a + a;
    count2++;
  }

  soma_b = 0;
  count2 = 0;
  digitalWrite(led, LOW);
  delay(1);
  while(count2 < leituras_intervalo){
    b = analogRead(sensor);
    soma_b = soma_b + b;
    count2++;
  }
  count2 = 0;

  c = ((soma_a/leituras_intervalo) - (soma_b/leituras_intervalo));
  vet[count] = c;
  soma = soma + c;
  count++;
  Serial.print(c);       //denoised signal
  Serial.print("\t");
  Serial.print(count);         //noise+signal
  Serial.print("\t");
  Serial.println();
  
  }//fim do while

  media10_10 = (soma/montante);
  Serial.println();
  Serial.print("Media(10_10):");
  Serial.print(media10_10);
  Serial.println();

  //calculando a variancia amostral
  for(i = 0; i < montante; i++){
    soma_var = soma_var + ( (vet[i] - media10_10)*(vet[i] - media10_10) );
  }
  variancia10_10 = sqrt(soma_var/(montante-1));
  Serial.print("Variancia(10_10):");
  Serial.print(variancia10_10);
  Serial.println();


  //TESTE 7 (SOMATORIO 3)
  leituras_intervalo = 15;
  soma = 0;
  count = 0;
  soma_var = 0;
  count2 = 0;
  for(i = 0; i < montante; i++){
    vet[i] = 0;
  }

  Serial.println("TESTE 15 leituras entre ON/OFF");

  while(count < montante){

  soma_a = 0;
  digitalWrite(led, HIGH);
  delay(1);
  while(count2 < leituras_intervalo){
    a = analogRead(sensor);
    soma_a = soma_a + a;
    count2++;
  }

  soma_b = 0;
  count2 = 0;
  digitalWrite(led, LOW);
  delay(1);
  while(count2 < leituras_intervalo){
    b = analogRead(sensor);
    soma_b = soma_b + b;
    count2++;
  }
  count2 = 0;

  c = ((soma_a/leituras_intervalo) - (soma_b/leituras_intervalo));
  vet[count] = c;
  soma = soma + c;
  count++;
  Serial.print(c);       //denoised signal
  Serial.print("\t");
  Serial.print(count);         //noise+signal
  Serial.print("\t");
  Serial.println();
  
  }//fim do while

  media15_15 = (soma/montante);
  Serial.println();
  Serial.print("Media(15_15):");
  Serial.print(media15_15);
  Serial.println();

  //calculando a variancia amostral
  for(i = 0; i < montante; i++){
    soma_var = soma_var + ( (vet[i] - media15_15)*(vet[i] - media15_15) );
  }
  variancia15_15 = sqrt(soma_var/(montante-1));
  Serial.print("Variancia(15_15):");
  Serial.print(variancia15_15);
  Serial.println();

  //TESTE 8 (SOMATORIO 4)
  leituras_intervalo = 20;
  soma = 0;
  count = 0;
  soma_var = 0;
  count2 = 0;
  for(i = 0; i < montante; i++){
    vet[i] = 0;
  }

  Serial.println("TESTE 20 leituras entre ON/OFF");

  while(count < montante){

  soma_a = 0;
  digitalWrite(led, HIGH);
  delay(1);
  while(count2 < leituras_intervalo){
    a = analogRead(sensor);
    soma_a = soma_a + a;
    count2++;
  }

  soma_b = 0;
  count2 = 0;
  digitalWrite(led, LOW);
  delay(1);
  while(count2 < leituras_intervalo){
    b = analogRead(sensor);
    soma_b = soma_b + b;
    count2++;
  }
  count2 = 0;

  c = ((soma_a/leituras_intervalo) - (soma_b/leituras_intervalo));
  vet[count] = c;
  soma = soma + c;
  count++;
  Serial.print(c);       //denoised signal
  Serial.print("\t");
  Serial.print(count);         //noise+signal
  Serial.print("\t");
  Serial.println();
  
  }//fim do while

  media20_20 = (soma/montante);
  /*
  Serial.println();
  Serial.print("Media(20_20):");
  Serial.print(media20_20);
  Serial.println();
  */

  //calculando a variancia amostral
  for(i = 0; i < montante; i++){
    soma_var = soma_var + ( (vet[i] - media20_20)*(vet[i] - media20_20) );
  }
  variancia20_20 = sqrt(soma_var/(montante-1));
  /*
  Serial.print("Variancia(20_20):");
  Serial.print(variancia20_20);
  Serial.println();
  */

  //PRINTS FINAIS
  Serial.println();
  Serial.print("Media(10ms):");
  Serial.print(media10);
  Serial.println();
   Serial.print("Variancia(10ms):");
  Serial.print(variancia10);
  Serial.println();
    Serial.println();
  Serial.print("Media(20ms):");
  Serial.print(media20);
  Serial.println();
   Serial.print("Variancia(20ms):");
  Serial.print(variancia20);
  Serial.println();
  Serial.println();
  Serial.print("Media(25ms):");
  Serial.print(media25);
  Serial.println();
    Serial.print("Variancia(25ms):");
  Serial.print(variancia25);
  Serial.println();
    Serial.println();
  Serial.print("Media(50ms):");
  Serial.print(media50);
  Serial.println();
    Serial.print("Variancia(50ms):");
  Serial.print(variancia50);
  Serial.println();
    Serial.println();
  Serial.print("Media(5_5):");
  Serial.print(media5_5);
  Serial.println();
    Serial.print("Variancia(5_5):");
  Serial.print(variancia5_5);
  Serial.println();
 Serial.println();
  Serial.print("Media(10_10):");
  Serial.print(media10_10);
  Serial.println();
    Serial.print("Variancia(10_10):");
  Serial.print(variancia10_10);
  Serial.println();
   Serial.println();
  Serial.print("Media(15_15):");
  Serial.print(media15_15);
  Serial.println();
   Serial.print("Variancia(15_15):");
  Serial.print(variancia15_15);
  Serial.println();
 Serial.println();
  Serial.print("Media(20_20):");
  Serial.print(media20_20);
  Serial.println();
    Serial.print("Variancia(20_20):");
  Serial.print(variancia20_20);
  Serial.println();





  break;//break do case 1


  case '2':
  Serial.println("Variaveis resetadas para teste");
  soma = 0;
  media10 = 0;
  variancia10 = 0;
  count = 0;
  soma_var = 0;
  for(i = 0; i < montante; i++){
    vet[i] = 0;
  }

  break;


  default:
  break;

  }//fim do switch

  }//fim do while

}

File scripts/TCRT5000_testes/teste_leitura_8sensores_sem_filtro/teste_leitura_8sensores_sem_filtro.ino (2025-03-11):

#define sensor1 32 // (1) sensor na placa principal

#define sensor2 25 // (2) primeira placa a esquerda
#define sensor3 26 // (3) segunda placa a esquerda 
#define sensor4 27 // (4) terceira placa a esquerda

#define sensor5 13 // (5) quarta placa (de frente pra principal)
//#define sensor6 4 // (6) terceira placa a direita
#define sensor6 14 // (6) terceira placa a direita 
#define sensor7 35 // (7) segundo a direita
#define sensor8 34 // (8) primeiro a direita

#define led1 23
#define led2 33
#define led3 16
#define led4 17
#define led5 15
#define led6 18
#define led7 19
#define led8 4


int tam_amostra = 5000;
int a1, a2, a3, a4, a5, a6, a7, a8;
float soma1 = 0, final1 = 0;
float soma2 = 0, final2 = 0;
float soma3 = 0, final3 = 0;
float soma4 = 0, final4 = 0;
float soma5 = 0, final5 = 0;
float soma6 = 0, final6 = 0;
float soma7 = 0, final7 = 0;
float soma8 = 0, final8 = 0;


int i = 0;
int printar = 1;

void setup()  
{  
  pinMode(sensor1, INPUT);

  pinMode(sensor2, INPUT);
  pinMode(sensor3, INPUT); 
  pinMode(sensor4, INPUT);

  pinMode(sensor5, INPUT); 
  pinMode(sensor6, INPUT);   
  pinMode(sensor7, INPUT); 
  pinMode(sensor8, INPUT); 

  pinMode(led1,OUTPUT);
  pinMode(led2,OUTPUT);
  pinMode(led3,OUTPUT);
  pinMode(led4,OUTPUT);
  pinMode(led5,OUTPUT);
  pinMode(led6,OUTPUT);
  pinMode(led7,OUTPUT);
  pinMode(led8,OUTPUT);

  Serial.begin(115200);  
}  
   
void loop()  
{ 
  while(i < tam_amostra){
  i++;
  digitalWrite(led1,HIGH);
  digitalWrite(led2,HIGH);
  digitalWrite(led3,HIGH);
  digitalWrite(led4,HIGH);
  digitalWrite(led5,HIGH);
  digitalWrite(led6,HIGH);
  digitalWrite(led7,HIGH); 
  digitalWrite(led8,HIGH);

  delayMicroseconds(500); 


  a1 =analogRead(sensor1);
  soma1 = soma1 + a1;

  a2 =analogRead(sensor2);
  soma2 = soma2 + a2;

  a3 =analogRead(sensor3);
  soma3 = soma3 + a3;

  a4 =analogRead(sensor4);
  soma4 = soma4 + a4;

  a5 =analogRead(sensor5);
  soma5 = soma5 + a5;

  a6 =analogRead(sensor6);
  soma6 = soma6 + a6;

  a7 =analogRead(sensor7);
  soma7 = soma7 + a7;

  a8 =analogRead(sensor8);
  soma8 = soma8 + a8;

  Serial.print(" A1: ");
  Serial.print(a1);

  Serial.print(" A2: ");
  Serial.print(a2);

  Serial.print(" A3: ");
  Serial.print(a3);

  Serial.print(" A4: ");
  Serial.print(a4);

  Serial.print(" A5: ");
  Serial.print(a5);

  Serial.print(" A6: ");
  Serial.print(a6);

  Serial.print(" A7: ");
  Serial.print(a7);

  Serial.print(" A8: ");
  Serial.print(a8);

  Serial.println();

delay(10);
}


final1 = soma1/tam_amostra;

final2 = soma2/tam_amostra;

final3 = soma3/tam_amostra;

final4 = soma4/tam_amostra;

final5 = soma5/tam_amostra;

final6 = soma6/tam_amostra;

final7 = soma7/tam_amostra;

final8 = soma8/tam_amostra;


while(printar){
 
  Serial.println();
  Serial.print("Média final(1): ");
  Serial.print(final1);
 
  Serial.print(" ");
  Serial.print("Média final(2): ");
  Serial.print(final2);

  Serial.print(" ");
  Serial.print("Média final(3): ");
  Serial.print(final3);

  Serial.print(" ");
  Serial.print("Média final(4): ");
  Serial.print(final4);

  Serial.print(" ");
  Serial.print("Média final(5): ");
  Serial.print(final5);

  Serial.print(" ");
  Serial.print("Média final(6): ");
  Serial.print(final6);

  Serial.print(" ");
  Serial.print("Média final(7): ");
  Serial.print(final7);

  Serial.print(" ");
  Serial.print("Média final(8): ");
  Serial.print(final8);

printar = 0;
}

}//fim do loop
